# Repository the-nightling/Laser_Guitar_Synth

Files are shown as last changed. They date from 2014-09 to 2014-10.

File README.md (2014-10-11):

Laser_Guitar_Synth
==================

The laser guitar synthesizer synthesizes guitar sounds using the Karplus-Strong algorithm.
An STM32F4 microcontroller is used.

The relevant pin connections can be found in the Hardware folder.
Six laser diodes were used to generate six lasers that are being used instead of actual guitar strings. Those are paired with six photodiodes and fed into a multiplexer.

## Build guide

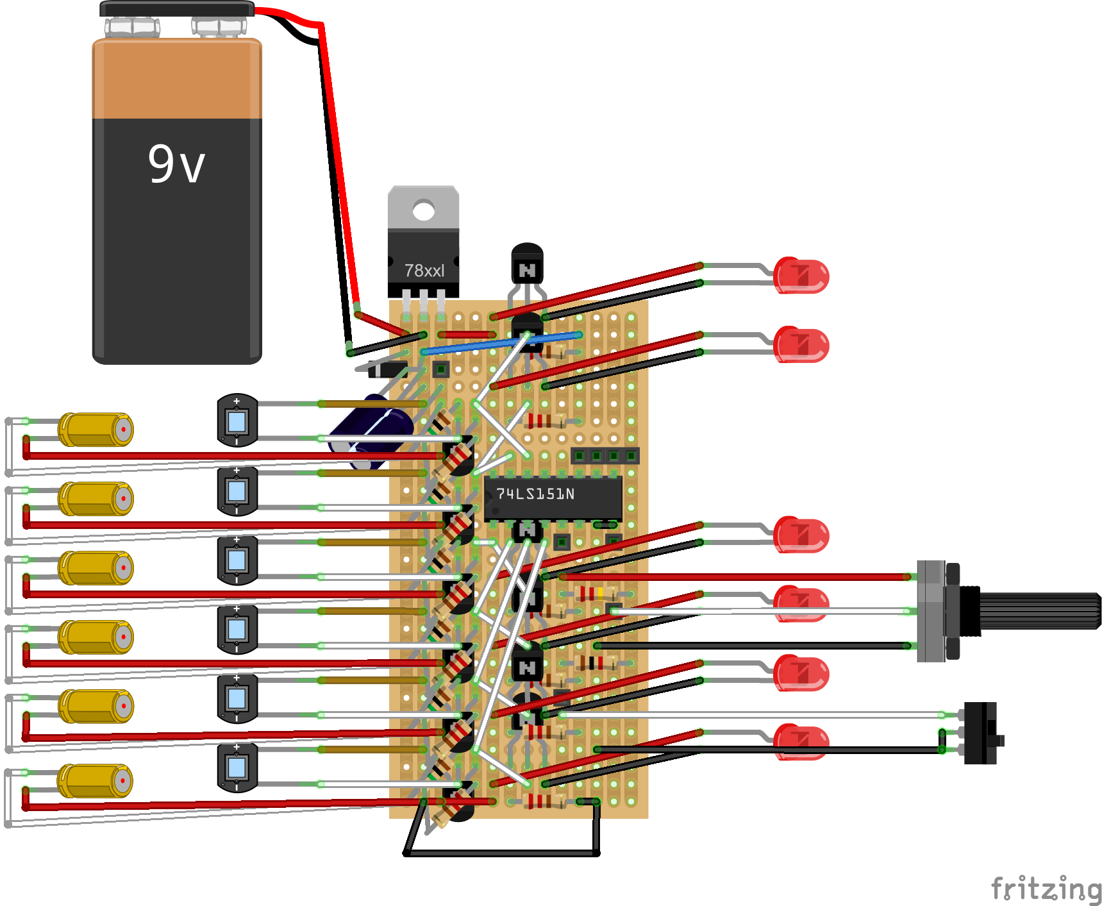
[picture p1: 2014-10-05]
Hardware/Veroboard Setup_bb.png

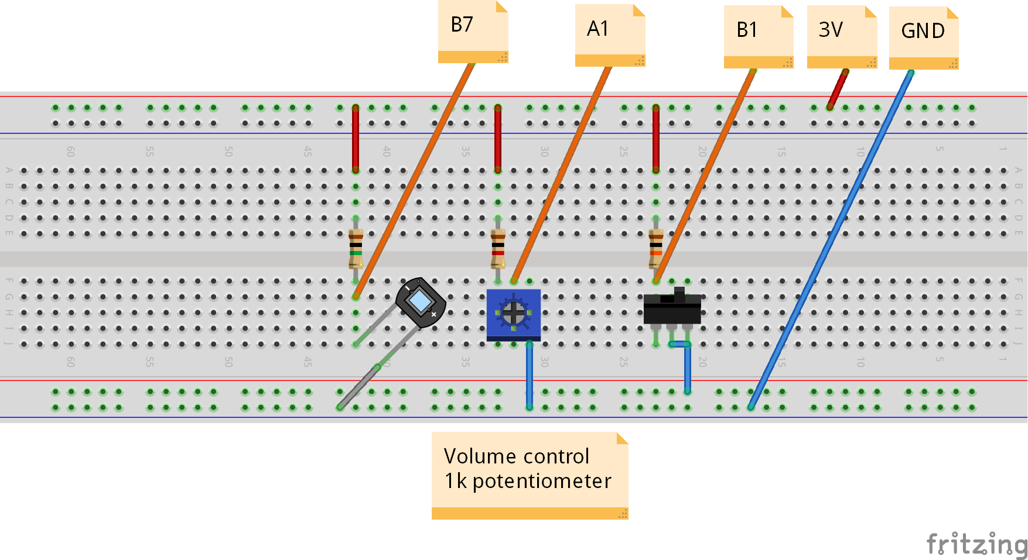
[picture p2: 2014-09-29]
Hardware/Breadboard Setup_bb.png

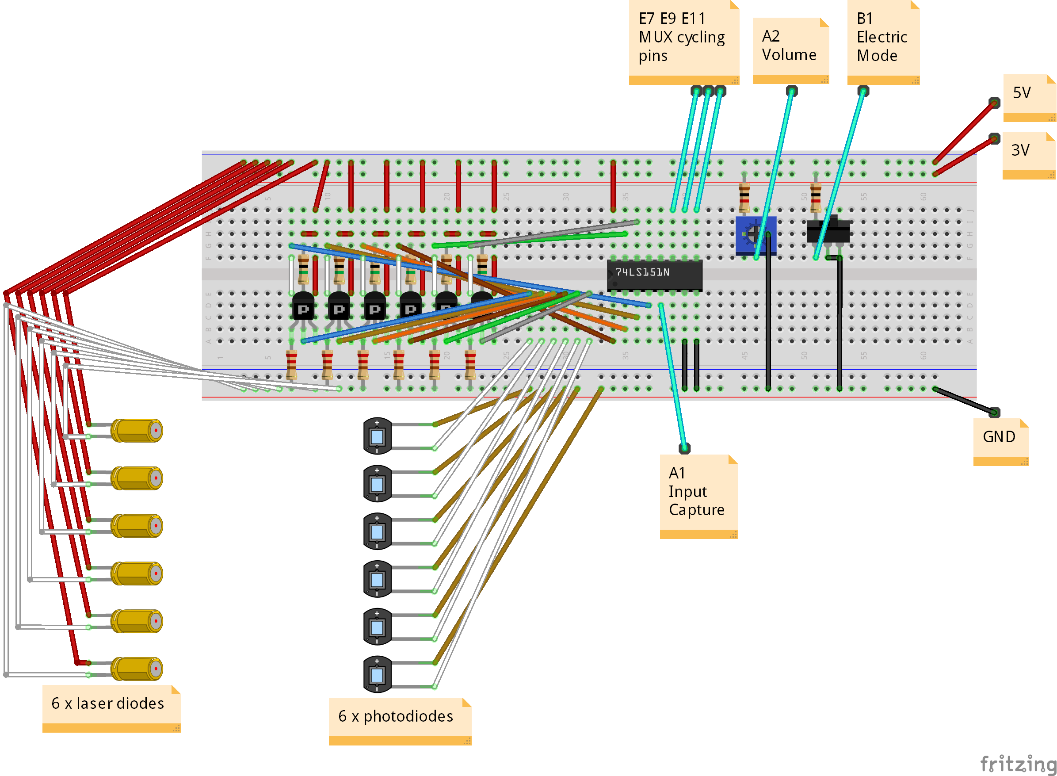
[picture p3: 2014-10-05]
Hardware/Breadboard Setup v2_bb.png

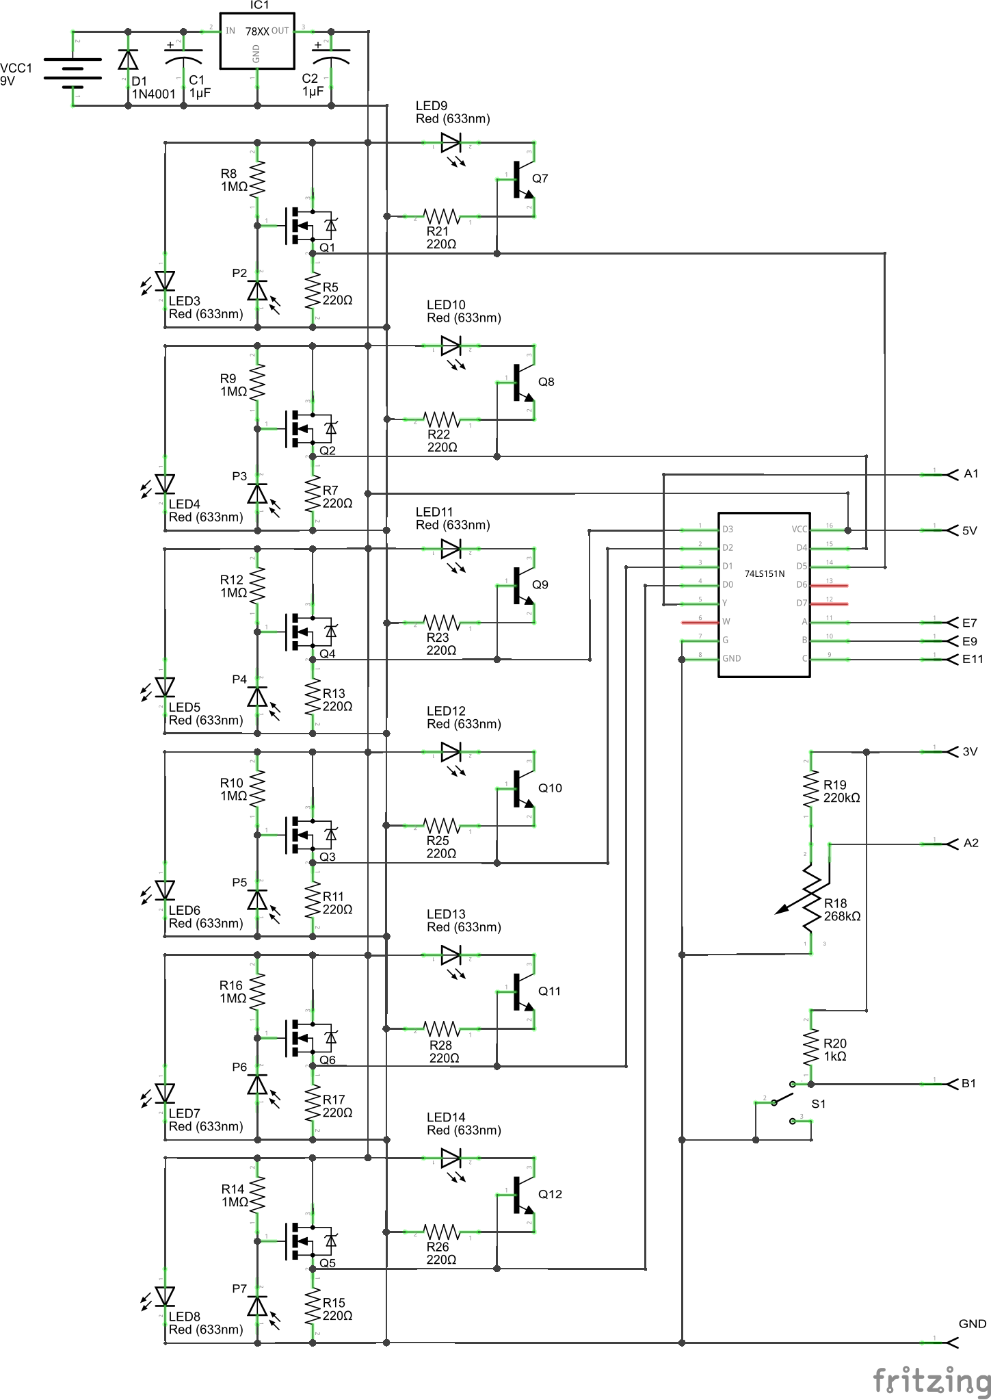
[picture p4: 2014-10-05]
Hardware/Veroboard Setup_schem.png

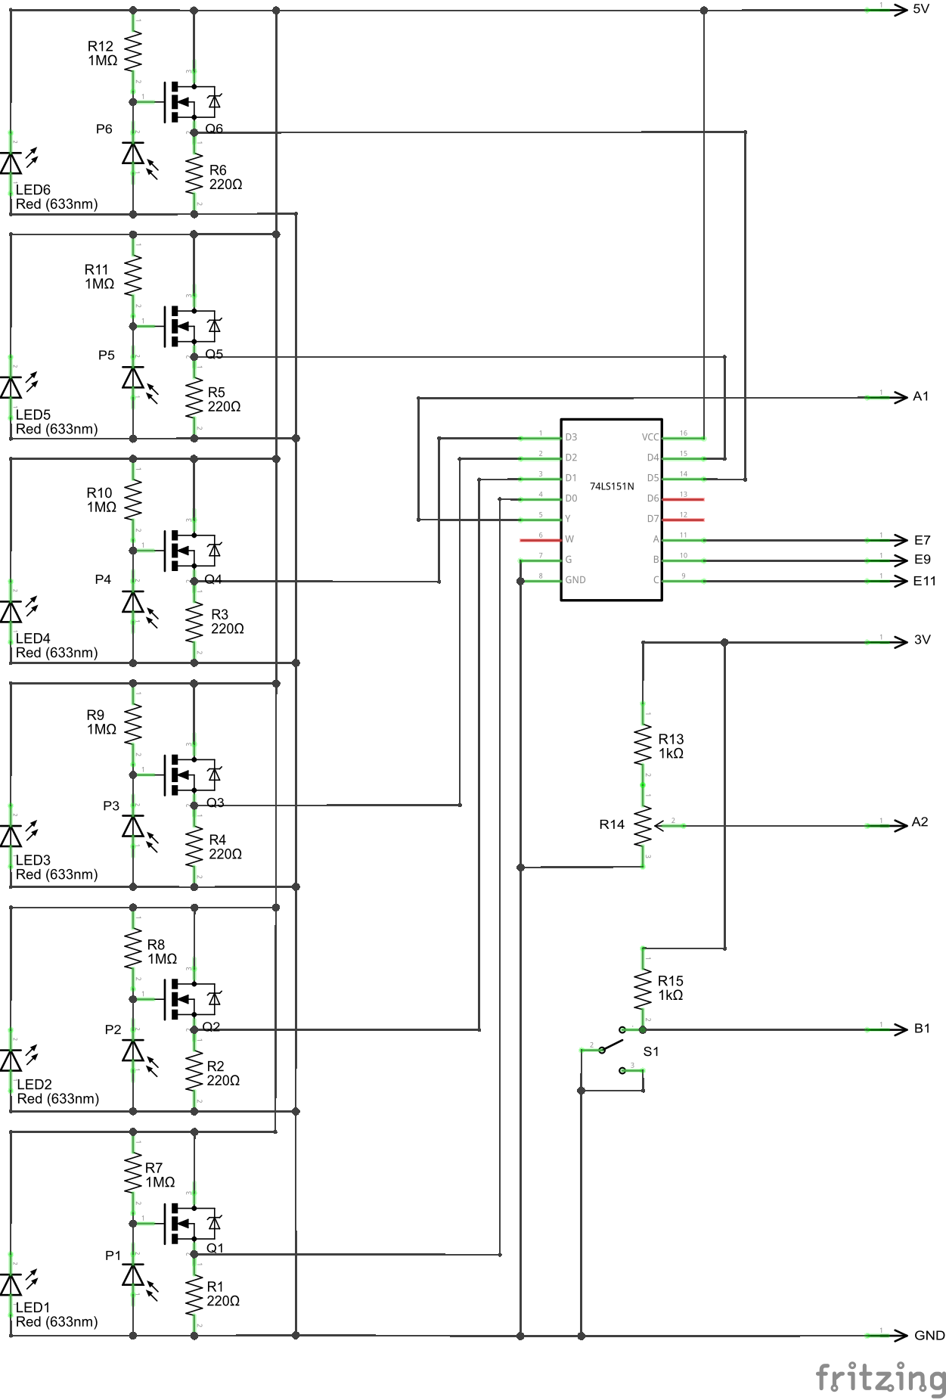
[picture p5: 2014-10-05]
Hardware/Breadboard Setup v2_schem.png

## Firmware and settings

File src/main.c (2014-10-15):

/**
 *****************************************************************************
 **
 ** EEE3074W Project
 ** Laser Guitar Synthesizer
 ** Team 10
 **
 ** Description:
 ** Upon an external trigger (plucking of laser string), the software:
 ** (i)   checks the volume, mode, note frequency and octave parameters
 ** (ii)  synthesizes the note corresponding to those parameters and saves the result in a buffer
 ** (iii) outputs the buffer contents via the on-board audio DAC
 **
 *****************************************************************************
 */

/* Includes */
#include "stm32f4xx.h"
#include "stm32f4_discovery.h"
#include "codec.h"
#include <math.h>

/* Private Macros */
#define OUTBUFFERSIZE 44100
#define DACBUFFERSIZE 600

/* Private Global Variables */
__IO uint8_t outBuffer[OUTBUFFERSIZE];	// stores synthesized note waveform
__IO uint16_t ADC1_val[7];				// volume knob and fret buttons voltage
__IO uint16_t IC1Value = 0;				// Stores length of beam break pulse (isn't being used)
__IO uint8_t string_plucked = 0;		// flag to indicate when a string was plucked
__IO uint8_t mux_enable = 1;			// flag to indicate if multiplexer is cycling through select pins
__IO uint8_t electrify = 0;				// flag to set/reset electric (reverb) mode
__IO uint8_t counter = 0;
__IO uint8_t stringNo = 6;				// default guitar string (laser)
__IO uint8_t octave = 4;				// default octave
__IO float noteFreq = 20.6;				// default note frequency
__IO float amplitude = 1.0;		// controls volume via duration of pluck (length of beam break can potentially change volume; not being used)
__IO float volume = 0.5;		// controls volume via volume knob
__IO uint32_t duration = 44100;	// controls duration of note


// Guitar notes buffer length reference
// C = 16.35	          C3 = 338, C4 = 168
// C#= 17.32	          C#3= 318, C#4= 160
// D = 18.35	          D3 = 300, D4 = 150
// Eb= 19.45	          Eb3= 284, Eb4= 142
// E = 20.60	E2 = 536, E3 = 268, E4 = 134
// F = 21.83	F2 = 506, F3 = 252, F4 = 126
// F#= 23.12	F#2= 476, F#3= 238, F#4= 120
// G = 24.50	G2 = 450, G3 = 226, G4 = 112
// G#= 25.96	G#2= 424, G#3= 212, G#4= 106
// A = 27.50	A2 = 400, A3 = 200
// Bb= 29.14	Bb2= 378, Bb3= 190
// B = 30.87	B2 = 358, B3 = 178

//				Free		Fret1		Fret2		Fret3		Fret4
// String 6:	E2 = 536	F2 = 506	F#2= 476	G2 = 450	G#2= 424
// String 5:	A2 = 400	Bb2= 378	B2 = 358	C3 = 338	C#3= 318
// String 4:	D3 = 300	Eb3= 284	E3 = 268	F3 = 252	F#3= 238
// String 3:	G3 = 226	G#3= 212	A3 = 200	Bb3= 190	B3 = 178
// String 2:	B3 = 178	C4 = 168	C#4= 160	D4 = 150	Eb4= 142
// String 1:	E4 = 134	F4 = 126	F#4= 120	G4 = 112	G#4= 106

/* Private Function Prototypes */
void RCC_Configuration(void);
void GPIO_Configuration(void);
void Timer_Configuration(void);
void NVIC_Configuration(void);
void RNG_Configuration(void);
void ADC_Configuration(void);



/**
 **===========================================================================
 **
 **  IRQ Handlers
 **
 **===========================================================================
 */
/*
 * Cycle through 6 laser strings via multiplexer
 */
void TIM2_IRQHandler(void)
{
	// Clear TIM2 interrupt pending bit
	if(TIM_GetITStatus(TIM2, TIM_IT_Update) != RESET)
	{
		TIM_ClearITPendingBit(TIM2, TIM_IT_Update);

		// cycle through 6 multiplexer pins while mux flag is high
		if (mux_enable == 1) {

			// set multiplexer input select pins
			if(counter == 0)
			{
				GPIOE->BSRRH = GPIO_Pin_7;
				GPIOE->BSRRH = GPIO_Pin_9;
				GPIOE->BSRRH = GPIO_Pin_11;
			}
			else if (counter == 1)
			{
				GPIOE->BSRRL = GPIO_Pin_7;
				GPIOE->BSRRH = GPIO_Pin_9;
				GPIOE->BSRRH = GPIO_Pin_11;
			}
			else if (counter == 2)
			{
				GPIOE->BSRRH = GPIO_Pin_7;
				GPIOE->BSRRL = GPIO_Pin_9;
				GPIOE->BSRRH = GPIO_Pin_11;
			}
			else if (counter == 3)
			{
				GPIOE->BSRRL = GPIO_Pin_7;
				GPIOE->BSRRL = GPIO_Pin_9;
				GPIOE->BSRRH = GPIO_Pin_11;
			}
			else if (counter == 4)
			{
				GPIOE->BSRRH = GPIO_Pin_7;
				GPIOE->BSRRH = GPIO_Pin_9;
				GPIOE->BSRRL = GPIO_Pin_11;
			}
			else if (counter == 5)
			{
				GPIOE->BSRRL = GPIO_Pin_7;
				GPIOE->BSRRH = GPIO_Pin_9;
				GPIOE->BSRRL = GPIO_Pin_11;
			}

			counter++;
			if(counter > 5)
			{
				counter = 0;
			}
		}
	}
}

/*
 * Trigger if laser string is plucked
 */
void TIM5_IRQHandler(void)
{
	// Clear TIM5 Capture compare interrupt pending bit (falling edge)
	if(TIM_GetITStatus(TIM5, TIM_IT_CC1) == SET) {
		TIM_ClearITPendingBit(TIM5, TIM_IT_CC1);

		// re-enable multiplexer pin cycling when laser is no longer broken
		mux_enable = 1;
	}

	// Clear TIM5 Capture compare interrupt pending bit (rising edge)
	if(TIM_GetITStatus(TIM5, TIM_IT_CC2) == SET) {
		TIM_ClearITPendingBit(TIM5, TIM_IT_CC2);

		// disable multiplexer pin cycling as soon as laser is broken
		mux_enable = 0;

		// Get the Input Capture value
		//IC1Value = TIM_GetCapture1(TIM5);		// for volume controlled by duration of pluck (not being used)
		volume = 10*((float)ADC1_val[0]/59456);

		//amplitude = (float)(volume)*(1-(float)IC1Value/0xFFFFFFFF);
		amplitude = (float)(volume);

		// Let us know that the string was plucked
		string_plucked = 1;
	}
}

/*
 * Electric mode switch stuff
 */
void EXTI1_IRQHandler(void)
{
	if(EXTI_GetITStatus(EXTI_Line1) != RESET)
	{
		if(GPIO_ReadInputDataBit(GPIOB, GPIO_Pin_1) == SET)
		{
			electrify = 1;
		}
		else
		{
			electrify = 0;
		}

		/* Clear the EXTI line 1 pending bit */
		EXTI_ClearITPendingBit(EXTI_Line1);
	}
}

/**
 **===========================================================================
 **
 **  Abstract: main program
 **
 **===========================================================================
 */
int main(void)
{
	volatile uint32_t sampleCounter = 0;
	volatile int16_t sample = 0;
	volatile uint8_t DACBuffer[DACBUFFERSIZE];		// buffer used for synthesis algorithm; length determines note frequency and octave
	volatile uint8_t tempBuffer[DACBUFFERSIZE];
	volatile uint8_t noiseBuffer[DACBUFFERSIZE];

	// Calculation of buffer length corresponding to note that needs to be played (using default values here)
	// duration/(note frequency x 2^octave) if odd, add 1
	uint16_t DACBufferSize = (uint16_t)(((float)44100/(noteFreq*pow(2, octave))));
	if(DACBufferSize & 0x00000001)
		DACBufferSize +=1;

	// initialising peripherals
	SystemInit();
	RCC_Configuration();
	GPIO_Configuration();
	Timer_Configuration();
	NVIC_Configuration();
	RNG_Configuration();
	codec_init();
	codec_ctrl_init();
	ADC_Configuration();

	// Fill buffer with white noise
	uint16_t n, m;
	uint32_t random = 0;
	for (n = 0; n<DACBUFFERSIZE; n++)
	{
		while(RNG_GetFlagStatus(RNG_FLAG_DRDY) == 0);
		random = RNG_GetRandomNumber();
		noiseBuffer[n] = (uint8_t)(((0xFF+1)/2)*(2*(((float)random)/0xFFFFFFFF)));
		DACBuffer[n] = noiseBuffer[n];
		RNG_ClearFlag(RNG_FLAG_DRDY);
	}

	// infinite loop contains synthesis and output code
	while(1)
	{
		if(string_plucked == 1)
		{
			// reset timer flag
			string_plucked = 0;

			// set note based on laser string plucked
			// and fret button pushed
			if(counter == 5)		// D3(String 2)
			{
				if(ADC1_val[5] > 60000)			// B3
				{
					noteFreq = 30.87;
					octave = 3;
				}
				else if(ADC1_val[5] > 42000)	// Eb4
				{
					noteFreq = 19.45;
					octave = 4;
				}
				else if(ADC1_val[5] > 39000)	// D4
				{
					noteFreq = 18.35;
					octave = 4;
				}
				else if(ADC1_val[5] > 35000)	// C#4
				{
					noteFreq = 17.32;
					octave = 4;
				}
				else if(ADC1_val[5] > 32000)	// C4
				{
					noteFreq = 16.35;
					octave = 4;
				}
				else							// B3
				{
					noteFreq = 30.87;
					octave = 3;
				}
			}
			else if(counter == 4)	// D2(String 3)
			{
				if(ADC1_val[4] > 60000)			// G3
				{
					noteFreq = 24.50;
					octave = 3;
				}
				else if(ADC1_val[4] > 42000)	// B3
				{
					noteFreq = 30.87;
					octave = 3;
				}
				else if(ADC1_val[4] > 39000)	// Bb3
				{
					noteFreq = 29.14;
					octave = 3;
				}
				else if(ADC1_val[4] > 35000)	// A3
				{
					noteFreq = 27.50;
					octave = 3;
				}
				else if(ADC1_val[4] > 32000)	// G#3
				{
					noteFreq = 25.96;
					octave = 3;
				}
				else							// G3
				{
					noteFreq = 24.50;
					octave = 3;
				}
			}
			else if(counter == 3)	// D1(String 4)
			{
				if(ADC1_val[3] > 60000)			// D3
				{
					noteFreq = 18.35;
					octave = 3;
				}
				else if(ADC1_val[3] > 42000)	// F#3
				{
					noteFreq = 23.12;
					octave = 3;
				}
				else if(ADC1_val[3] > 39000)	// F3
				{
					noteFreq = 21.83;
					octave = 3;
				}
				else if(ADC1_val[3] > 35000)	// E3
				{
					noteFreq = 20.60;
					octave = 3;
				}
				else if(ADC1_val[3] > 32000)	// Eb3
				{
					noteFreq = 19.45;
					octave = 3;
				}
				else							// D3
				{
					noteFreq = 18.35;
					octave = 3;
				}
			}
			else if(counter == 2)	// D0(String 5)
			{
				if(ADC1_val[2] > 60000)			// A2
				{
					noteFreq = 27.50;
					octave = 2;
				}
				else if(ADC1_val[2] > 42000)	// C#3
				{
					noteFreq = 17.32;
					octave = 3;
				}
				else if(ADC1_val[2] > 39000)	// C3
				{
					noteFreq = 16.35;
					octave = 3;
				}
				else if(ADC1_val[2] > 35000)	// B2
				{
					noteFreq = 30.87;
					octave = 2;
				}
				else if(ADC1_val[2] > 32000)	// Bb2
				{
					noteFreq = 29.14;
					octave = 2;
				}
				else							// A2
				{
					noteFreq = 27.50;
					octave = 2;
				}
			}
			else if(counter == 1)	// D5(String 6)
			{
				if(ADC1_val[1] > 60000)			// E2
				{
					noteFreq = 20.60;
					octave = 2;
				}
				else if(ADC1_val[1] > 42000)	// G#2
				{
					noteFreq = 25.96;
					octave = 2;
				}
				else if(ADC1_val[1] > 39000)	// G2
				{
					noteFreq = 24.50;
					octave = 2;
				}
				else if(ADC1_val[1] > 35000)	// F#2
				{
					noteFreq = 23.12;
					octave = 2;
				}
				else if(ADC1_val[1] > 32000)	// F2
				{
					noteFreq = 21.83;
					octave = 2;
				}
				else							// E2
				{
					noteFreq = 20.60;
					octave = 2;
				}
			}
			else if(counter == 0)	// D4(String 1)
			{
				if(ADC1_val[6] > 60000)			// E4
				{
					noteFreq = 20.60;
					octave = 4;
				}
				else if(ADC1_val[6] > 42000)	// G#4
				{
					noteFreq = 25.96;
					octave = 4;
				}
				else if(ADC1_val[6] > 39000)	// G4
				{
					noteFreq = 24.50;
					octave = 4;
				}
				else if(ADC1_val[6] > 35000)	// F#4
				{
					noteFreq = 23.12;
					octave = 4;
				}
				else if(ADC1_val[6] > 32000)	// F4
				{
					noteFreq = 21.83;
					octave = 4;
				}
				else							// E4
				{
					noteFreq = 20.60;
					octave = 4;
				}
			}

			// update buffer length according to note desired
			DACBufferSize = (uint16_t)(((float)44100/(noteFreq*pow(2, octave))));
			if(DACBufferSize & 0x00000001)
				DACBufferSize +=1;

			// Synthesize note
			volatile uint16_t i;
			volatile uint16_t j = 0;
			for(i = 0; i < duration; i++)
			{
				// send silence to audio DAC while note is being synthesized (gets rid of static noise)
				if (SPI_I2S_GetFlagStatus(CODEC_I2S, SPI_I2S_FLAG_TXE))
				{
					SPI_I2S_SendData(CODEC_I2S, 0);
				}

				// karplus-strong algorithm
				if(j != DACBufferSize-1)
				{
					tempBuffer[j] = (uint8_t)(((DACBuffer[j]+DACBuffer[j+1])/2.0)*0.999);
				}
				else
				{
					tempBuffer[j] = (uint8_t)(((DACBuffer[j]+tempBuffer[0])/2.0)*0.999);
				}
				outBuffer[i] = (uint8_t)tempBuffer[j];

				// electric mode (clips waveform)
				if(electrify == 1 && outBuffer[i] >= 105)
				{
					//outBuffer[i] = 55;
				}
				else if(electrify == 1 && outBuffer[i] < 105)
				{
					outBuffer[i] = 180;
				}

				j++;

				// values synthesized are re-used to synthesize newer values (simulates a queue)
				if(j == DACBufferSize)
				{
					for(n=0; n < DACBufferSize; n++)
					{
						DACBuffer[n] = tempBuffer[n];

						// send silence to audio DAC while note is being synthesized (gets rid of static noise)
						if (SPI_I2S_GetFlagStatus(CODEC_I2S, SPI_I2S_FLAG_TXE))
						{
							SPI_I2S_SendData(CODEC_I2S, 0);
						}
					}
					j = 0;
				}

			}

			// determines where in the output buffer we should start sending values to audioDAC
			// helps get rid of some delay
			n = 1000;

			// output sound
			while(1)
			{
				// if a new string has been plucked, stop outputting and re-start synthesis
				if(string_plucked == 1) {
					break;
				}

				// output sound
				if (SPI_I2S_GetFlagStatus(CODEC_I2S, SPI_I2S_FLAG_TXE))
				{
					SPI_I2S_SendData(CODEC_I2S, sample);

					//only update on every second sample to ensure that L & R channels have the same sample value
					if (sampleCounter & 0x00000001)
					{
						if(n >= duration)
						{
							n = 0;

							break;	// exit loop when note ends
						}

						sample = (int16_t)(amplitude*outBuffer[n]);

						// change increment value to change frequency (should not be used)
						n += 1;
					}
					sampleCounter++;
				}

				if (sampleCounter == 96000)
				{
					sampleCounter = 0;
				}
			}

			// fill buffer with white noise again
			for(m=0; m < DACBufferSize; m++)
			{
				DACBuffer[m] = noiseBuffer[m];

				// send silence to audio DAC while no note is being played (gets rid of static noise)
				if (SPI_I2S_GetFlagStatus(CODEC_I2S, SPI_I2S_FLAG_TXE))
				{
					SPI_I2S_SendData(CODEC_I2S, 0);
				}
			}
		}

		// while laser not broken
		// send silence to audio DAC while no note is being played (gets rid of static noise)
		if (SPI_I2S_GetFlagStatus(CODEC_I2S, SPI_I2S_FLAG_TXE))
		{
			SPI_I2S_SendData(CODEC_I2S, 0);
		}
	}
}



void RCC_Configuration(void)
{
	// enable clock for GPIOA, GPIOB, GPIOC, GPIOE and DMA2
	RCC_AHB1PeriphClockCmd(RCC_AHB1Periph_GPIOA|RCC_AHB1Periph_GPIOB|RCC_AHB1Periph_GPIOC|RCC_AHB1Periph_GPIOE|RCC_AHB1Periph_DMA2, ENABLE);

	// enable clock for Random Number Generator
	RCC_AHB2PeriphClockCmd(RCC_AHB2Periph_RNG, ENABLE);

	// enable clock for timers 2 and 5
	RCC_APB1PeriphClockCmd(RCC_APB1Periph_TIM5|RCC_APB1Periph_TIM2, ENABLE);

	// enable clock for SYSCFG for EXTI
	RCC_APB2PeriphClockCmd(RCC_APB2Periph_SYSCFG|RCC_APB2Periph_ADC1, ENABLE);
}

void GPIO_Configuration(void)
{
	GPIO_InitTypeDef GPIO_InitStructure;

	/* TIM5 channel2 configuration : PA.01 */
	GPIO_InitStructure.GPIO_Pin   = GPIO_Pin_1;
	GPIO_InitStructure.GPIO_Mode  = GPIO_Mode_AF;
	GPIO_InitStructure.GPIO_Speed = GPIO_Speed_100MHz;
	GPIO_InitStructure.GPIO_OType = GPIO_OType_PP;
	GPIO_InitStructure.GPIO_PuPd  = GPIO_PuPd_NOPULL;

	GPIO_Init(GPIOA, &GPIO_InitStructure);

	/* Connect TIM pin to AF2 */
	GPIO_PinAFConfig(GPIOA, GPIO_PinSource1, GPIO_AF_TIM5);

	/* Electric mode switch configuration: PB.01 */
	GPIO_InitStructure.GPIO_Pin = GPIO_Pin_1;
	GPIO_InitStructure.GPIO_Mode = GPIO_Mode_IN;
	GPIO_InitStructure.GPIO_PuPd = GPIO_PuPd_NOPULL;
	GPIO_Init(GPIOB, &GPIO_InitStructure);

	/* Connect EXTI Line to GPIO Pin */
	SYSCFG_EXTILineConfig(EXTI_PortSourceGPIOB, EXTI_PinSource1);

	EXTI_InitTypeDef EXTI_InitStructure;

	/* Configure EXTI line */
	EXTI_InitStructure.EXTI_Line = EXTI_Line1;
	EXTI_InitStructure.EXTI_Mode = EXTI_Mode_Interrupt;
	EXTI_InitStructure.EXTI_Trigger = EXTI_Trigger_Rising_Falling;
	EXTI_InitStructure.EXTI_LineCmd = ENABLE;
	EXTI_Init(&EXTI_InitStructure);

	/* Volume pin configuration */
	GPIO_InitStructure.GPIO_Mode = GPIO_Mode_AN;
	GPIO_InitStructure.GPIO_Pin = GPIO_Pin_2 | GPIO_Pin_3;
	GPIO_InitStructure.GPIO_PuPd = GPIO_PuPd_NOPULL;

	GPIO_Init(GPIOA, &GPIO_InitStructure);

	GPIO_InitStructure.GPIO_Mode = GPIO_Mode_AN;
	GPIO_InitStructure.GPIO_Pin = GPIO_Pin_0;
	GPIO_InitStructure.GPIO_PuPd = GPIO_PuPd_NOPULL;

	GPIO_Init(GPIOB, &GPIO_InitStructure);

	GPIO_InitStructure.GPIO_Mode = GPIO_Mode_AN;
	GPIO_InitStructure.GPIO_Pin = GPIO_Pin_1 | GPIO_Pin_2 | GPIO_Pin_4 | GPIO_Pin_5;
	GPIO_InitStructure.GPIO_PuPd = GPIO_PuPd_NOPULL;

	GPIO_Init(GPIOC, &GPIO_InitStructure);

	/* Multiplexer switching configuration */
	GPIO_InitStructure.GPIO_Pin = GPIO_Pin_7;
	GPIO_InitStructure.GPIO_Mode = GPIO_Mode_OUT;
	GPIO_InitStructure.GPIO_OType = GPIO_OType_PP;
	GPIO_InitStructure.GPIO_PuPd = GPIO_PuPd_UP;
	GPIO_InitStructure.GPIO_Speed = GPIO_Speed_50MHz;
	GPIO_Init(GPIOE, &GPIO_InitStructure);

	GPIO_InitStructure.GPIO_Pin = GPIO_Pin_9;
	GPIO_Init(GPIOE, &GPIO_InitStructure);

	GPIO_InitStructure.GPIO_Pin = GPIO_Pin_11;
	GPIO_Init(GPIOE, &GPIO_InitStructure);

}

void NVIC_Configuration(void)
{
	NVIC_InitTypeDef NVIC_InitStructure;
	NVIC_PriorityGroupConfig(NVIC_PriorityGroup_4);

	/* Enable the TIM5 global Interrupt */
	NVIC_InitStructure.NVIC_IRQChannel = TIM5_IRQn;
	NVIC_InitStructure.NVIC_IRQChannelPreemptionPriority = 0;
	NVIC_InitStructure.NVIC_IRQChannelSubPriority = 1;
	NVIC_InitStructure.NVIC_IRQChannelCmd = ENABLE;

	NVIC_Init(&NVIC_InitStructure);

	/* Enable and set Button EXTI Interrupt to the lowest priority */
	NVIC_InitStructure.NVIC_IRQChannel = EXTI1_IRQn;
	NVIC_InitStructure.NVIC_IRQChannelPreemptionPriority = 1;
	NVIC_InitStructure.NVIC_IRQChannelSubPriority = 1;
	NVIC_InitStructure.NVIC_IRQChannelCmd = ENABLE;

	NVIC_Init(&NVIC_InitStructure);

	/* Enable the TIM2 global Interrupt*/
	NVIC_InitStructure.NVIC_IRQChannel = TIM2_IRQn;
	NVIC_InitStructure.NVIC_IRQChannelPreemptionPriority = 2;
	NVIC_InitStructure.NVIC_IRQChannelSubPriority = 1;
	NVIC_InitStructure.NVIC_IRQChannelCmd = ENABLE;

	NVIC_Init(&NVIC_InitStructure);
}

void Timer_Configuration(void)
{
	TIM_ICInitTypeDef  TIM_ICInitStructure;
	TIM_TimeBaseInitTypeDef  TIM_TimeBaseStructure;

	TIM_TimeBaseStructure.TIM_Period = 0xFFFFFFFF;
	TIM_TimeBaseStructure.TIM_Prescaler = 2000;
	TIM_TimeBaseStructure.TIM_ClockDivision = 0;
	TIM_TimeBaseStructure.TIM_CounterMode = TIM_CounterMode_Up;
	TIM_TimeBaseInit(TIM5, &TIM_TimeBaseStructure);

	TIM_ICInitStructure.TIM_Channel = TIM_Channel_2;
	TIM_ICInitStructure.TIM_ICPolarity = TIM_ICPolarity_Rising;
	TIM_ICInitStructure.TIM_ICSelection = TIM_ICSelection_DirectTI;
	TIM_ICInitStructure.TIM_ICPrescaler = TIM_ICPSC_DIV1;
	TIM_ICInitStructure.TIM_ICFilter = 0x3;

	TIM_PWMIConfig(TIM5, &TIM_ICInitStructure);

	/* Select the TIM5 Input Trigger: TI2FP2 */
	TIM_SelectInputTrigger(TIM5, TIM_TS_TI2FP2);

	/* Select the slave Mode: Reset Mode */
	TIM_SelectSlaveMode(TIM5, TIM_SlaveMode_Reset);
	TIM_SelectMasterSlaveMode(TIM5,TIM_MasterSlaveMode_Enable);

	/* TIM enable counter */
	TIM_Cmd(TIM5, ENABLE);

	/* Enable the CC1 Interrupt Request */
	TIM_ITConfig(TIM5, TIM_IT_CC1 | TIM_IT_CC2, ENABLE);

	// TIM2 Setup

	TIM_TimeBaseStructInit(&TIM_TimeBaseStructure);

	TIM_TimeBaseStructure.TIM_Period = 840-1;
	TIM_TimeBaseStructure.TIM_Prescaler = 1-1;
	TIM_TimeBaseStructure.TIM_ClockDivision = 0;
	TIM_TimeBaseStructure.TIM_CounterMode = TIM_CounterMode_Up;

	TIM_TimeBaseInit(TIM2, &TIM_TimeBaseStructure);

	/* Enable the Interrupt Request */
	TIM_ITConfig(TIM2, TIM_IT_Update, ENABLE);

	TIM_Cmd(TIM2, ENABLE);
}


void ADC_Configuration(void)
{
	ADC_InitTypeDef ADC_InitStruct;
	ADC_CommonInitTypeDef ADC_CommonInitStruct;
	DMA_InitTypeDef DMA_InitStruct;

	DMA_InitStruct.DMA_BufferSize = 7;
	DMA_InitStruct.DMA_Channel = DMA_Channel_0;
	DMA_InitStruct.DMA_DIR = DMA_DIR_PeripheralToMemory;
	DMA_InitStruct.DMA_FIFOMode = DMA_FIFOMode_Disable;
	DMA_InitStruct.DMA_FIFOThreshold = DMA_FIFOThreshold_HalfFull;
	DMA_InitStruct.DMA_Memory0BaseAddr = (uint32_t)&ADC1_val[0];
	DMA_InitStruct.DMA_MemoryBurst = DMA_MemoryBurst_Single;
	DMA_InitStruct.DMA_MemoryDataSize = DMA_MemoryDataSize_HalfWord;
	DMA_InitStruct.DMA_MemoryInc = DMA_MemoryInc_Enable;
	DMA_InitStruct.DMA_Mode = DMA_Mode_Circular;
	DMA_InitStruct.DMA_PeripheralBaseAddr = (uint32_t) &ADC1->DR;
	DMA_InitStruct.DMA_PeripheralBurst = DMA_PeripheralBurst_Single;
	DMA_InitStruct.DMA_PeripheralDataSize = DMA_PeripheralDataSize_HalfWord;
	DMA_InitStruct.DMA_PeripheralInc = DMA_PeripheralInc_Disable;
	DMA_InitStruct.DMA_Priority = DMA_Priority_High;
	DMA_Init(DMA2_Stream4, &DMA_InitStruct);
	DMA_Cmd(DMA2_Stream4, ENABLE);

	ADC_CommonInitStruct.ADC_DMAAccessMode = ADC_DMAAccessMode_Disabled;
	ADC_CommonInitStruct.ADC_Mode = ADC_Mode_Independent;
	ADC_CommonInitStruct.ADC_Prescaler = ADC_Prescaler_Div2;
	ADC_CommonInitStruct.ADC_TwoSamplingDelay = ADC_TwoSamplingDelay_5Cycles;
	ADC_CommonInit(&ADC_CommonInitStruct);

	ADC_InitStruct.ADC_ContinuousConvMode = ENABLE;
	ADC_InitStruct.ADC_DataAlign = ADC_DataAlign_Right;
	ADC_InitStruct.ADC_ExternalTrigConv = ADC_ExternalTrigConvEdge_None;
	ADC_InitStruct.ADC_ExternalTrigConv = ADC_ExternalTrigConv_T1_CC1;
	ADC_InitStruct.ADC_NbrOfConversion = 7;
	ADC_InitStruct.ADC_Resolution = ADC_Resolution_12b;
	ADC_InitStruct.ADC_ScanConvMode = ENABLE;
	ADC_Init(ADC1, &ADC_InitStruct);

	ADC_RegularChannelConfig(ADC1, ADC_Channel_2, 1, ADC_SampleTime_112Cycles); //PA2
	ADC_RegularChannelConfig(ADC1, ADC_Channel_3, 2, ADC_SampleTime_112Cycles); //PA3
	ADC_RegularChannelConfig(ADC1, ADC_Channel_8, 3, ADC_SampleTime_112Cycles); //PB0
	ADC_RegularChannelConfig(ADC1, ADC_Channel_11, 4, ADC_SampleTime_112Cycles); //PC1
	ADC_RegularChannelConfig(ADC1, ADC_Channel_12, 5, ADC_SampleTime_112Cycles); //PC2
	ADC_RegularChannelConfig(ADC1, ADC_Channel_14, 6, ADC_SampleTime_112Cycles); //PC4
	ADC_RegularChannelConfig(ADC1, ADC_Channel_15, 7, ADC_SampleTime_112Cycles); //PC5

	ADC_DMARequestAfterLastTransferCmd(ADC1, ENABLE);
	ADC_DMACmd(ADC1, ENABLE);
	ADC_Cmd(ADC1, ENABLE);

	ADC_SoftwareStartConv(ADC1);
}

// Random Number Generator setup
void RNG_Configuration(void)
{
	RNG_Cmd(ENABLE);
}

/*
 * Callback used by stm32f4_discovery_audio_codec.c.
 * Refer to stm32f4_discovery_audio_codec.h for more info.
 */
void EVAL_AUDIO_TransferComplete_CallBack(uint32_t pBuffer, uint32_t Size){
	/* TODO, implement your code here */
	return;
}

/*
 * Callback used by stm324xg_eval_audio_codec.c.
 * Refer to stm324xg_eval_audio_codec.h for more info.
 */
uint16_t EVAL_AUDIO_GetSampleCallBack(void){
	/* TODO, implement your code here */
	return -1;
}

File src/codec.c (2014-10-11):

//*************************************
//
//  codec related functions
//
//	adapted from A.Finkelmeyer
//  http://www.mind-dump.net/configuring-the-stm32f4-discovery-for-audio
//
//*************************************

#include "codec.h"

void codec_init()
{
	// enable GPIOA, GPIOB, GPIOC, GPIOD clocks
	RCC_AHB1PeriphClockCmd(RCC_AHB1Periph_GPIOA | RCC_AHB1Periph_GPIOB | RCC_AHB1Periph_GPIOC | RCC_AHB1Periph_GPIOD, ENABLE);

	//enable I2S and I2C clocks
	RCC_APB1PeriphClockCmd(RCC_APB1Periph_I2C1 | RCC_APB1Periph_SPI3, ENABLE);
	RCC_PLLI2SCmd(ENABLE);

	// setting up GPIO for codec use
	GPIO_InitTypeDef PinInitStruct;
	GPIO_StructInit(&PinInitStruct);

	//Reset pin as GPIO
	PinInitStruct.GPIO_Pin = CODEC_RESET_PIN;	// pin D4 is codec reset pin
	PinInitStruct.GPIO_Mode = GPIO_Mode_OUT;
	PinInitStruct.GPIO_PuPd = GPIO_PuPd_DOWN;
	PinInitStruct.GPIO_OType = GPIO_OType_PP;
	PinInitStruct.GPIO_Speed = GPIO_Speed_50MHz;

	GPIO_Init(GPIOD, &PinInitStruct);
	GPIO_ResetBits(GPIOD, CODEC_RESET_PIN);	//keep Codec off for now

	// I2C pins
	PinInitStruct.GPIO_Pin = I2C_SCL_PIN | I2C_SDA_PIN;
	PinInitStruct.GPIO_Mode = GPIO_Mode_AF;
	PinInitStruct.GPIO_PuPd = GPIO_PuPd_NOPULL;
	PinInitStruct.GPIO_OType = GPIO_OType_OD;
	PinInitStruct.GPIO_Speed = GPIO_Speed_50MHz;
	GPIO_Init(GPIOB, &PinInitStruct);

	GPIO_PinAFConfig(GPIOB, GPIO_PinSource6, GPIO_AF_I2C1);	// pin B6 is SCL pin
	GPIO_PinAFConfig(GPIOB, GPIO_PinSource9, GPIO_AF_I2C1);	// pin B9 is SDA pin

	// I2S pins
	PinInitStruct.GPIO_Pin = I2S3_SCLK_PIN | I2S3_SD_PIN | I2S3_MCLK_PIN;	// pin C7 is MCLK; pin C10 is SCLK; pin C12 is SDIN
	PinInitStruct.GPIO_OType = GPIO_OType_PP;

	GPIO_Init(GPIOC, &PinInitStruct);
	GPIO_PinAFConfig(GPIOC, GPIO_PinSource7, GPIO_AF_SPI3);
	GPIO_PinAFConfig(GPIOC, GPIO_PinSource10, GPIO_AF_SPI3);
	GPIO_PinAFConfig(GPIOC, GPIO_PinSource12, GPIO_AF_SPI3);

	PinInitStruct.GPIO_Pin = I2S3_WS_PIN;	// pin A4 is LRCK/AIN1x

	GPIO_Init(GPIOA, &PinInitStruct);
	GPIO_PinAFConfig(GPIOA, GPIO_PinSource4, GPIO_AF_SPI3);


	I2S_InitTypeDef I2S_InitType;

	// configure I2S port
	SPI_I2S_DeInit(CODEC_I2S);
	I2S_InitType.I2S_AudioFreq = I2S_AudioFreq_48k;
	I2S_InitType.I2S_MCLKOutput = I2S_MCLKOutput_Enable;
	I2S_InitType.I2S_DataFormat = I2S_DataFormat_16b;
	I2S_InitType.I2S_Mode = I2S_Mode_MasterTx;
	I2S_InitType.I2S_Standard = I2S_Standard_Phillips;
	I2S_InitType.I2S_CPOL = I2S_CPOL_Low;

	I2S_Init(CODEC_I2S, &I2S_InitType);


	I2C_InitTypeDef I2C_InitType;

	// configure I2C port
	I2C_DeInit(CODEC_I2C);
	I2C_InitType.I2C_ClockSpeed = 100000;
	I2C_InitType.I2C_Mode = I2C_Mode_I2C;
	I2C_InitType.I2C_OwnAddress1 = CORE_I2C_ADDRESS;
	I2C_InitType.I2C_Ack = I2C_Ack_Enable;
	I2C_InitType.I2C_AcknowledgedAddress = I2C_AcknowledgedAddress_7bit;
	I2C_InitType.I2C_DutyCycle = I2C_DutyCycle_2;

	I2C_Cmd(CODEC_I2C, ENABLE);
	I2C_Init(CODEC_I2C, &I2C_InitType);
}


void codec_ctrl_init()
{
	uint32_t delaycount;
	uint8_t CodecCommandBuffer[5];

	uint8_t regValue = 0xFF;

	GPIO_SetBits(GPIOD, CODEC_RESET_PIN);
	delaycount = 1000000;
	while (delaycount > 0)
	{
		delaycount--;
	}
	//keep codec OFF
	CodecCommandBuffer[0] = CODEC_MAP_PLAYBACK_CTRL1;
	CodecCommandBuffer[1] = 0x01;
	send_codec_ctrl(CodecCommandBuffer, 2);

	//begin initialization sequence (p. 32)
	CodecCommandBuffer[0] = 0x00;
	CodecCommandBuffer[1] = 0x99;
	send_codec_ctrl(CodecCommandBuffer, 2);

	CodecCommandBuffer[0] = 0x47;
	CodecCommandBuffer[1] = 0x80;
	send_codec_ctrl(CodecCommandBuffer, 2);

	regValue = read_codec_register(0x32);

	CodecCommandBuffer[0] = 0x32;
	CodecCommandBuffer[1] = regValue | 0x80;
	send_codec_ctrl(CodecCommandBuffer, 2);

	regValue = read_codec_register(0x32);

	CodecCommandBuffer[0] = 0x32;
	CodecCommandBuffer[1] = regValue & (~0x80);
	send_codec_ctrl(CodecCommandBuffer, 2);

	CodecCommandBuffer[0] = 0x00;
	CodecCommandBuffer[1] = 0x00;
	send_codec_ctrl(CodecCommandBuffer, 2);
	//end of initialization sequence

	CodecCommandBuffer[0] = CODEC_MAP_PWR_CTRL2;
	CodecCommandBuffer[1] = 0xAF;
	send_codec_ctrl(CodecCommandBuffer, 2);

	CodecCommandBuffer[0] = CODEC_MAP_PLAYBACK_CTRL1;
	CodecCommandBuffer[1] = 0x70;
	send_codec_ctrl(CodecCommandBuffer, 2);

	CodecCommandBuffer[0] = CODEC_MAP_CLK_CTRL;
	CodecCommandBuffer[1] = 0x81; //auto detect clock
	send_codec_ctrl(CodecCommandBuffer, 2);

	CodecCommandBuffer[0] = CODEC_MAP_IF_CTRL1;
	CodecCommandBuffer[1] = 0x07;
	send_codec_ctrl(CodecCommandBuffer, 2);

	CodecCommandBuffer[0] = 0x0A;
	CodecCommandBuffer[1] = 0x00;
	send_codec_ctrl(CodecCommandBuffer, 2);

	CodecCommandBuffer[0] = 0x27;
	CodecCommandBuffer[1] = 0x00;
	send_codec_ctrl(CodecCommandBuffer, 2);

	CodecCommandBuffer[0] = 0x1A | CODEC_MAPBYTE_INC;
	CodecCommandBuffer[1] = 0x0A;
	CodecCommandBuffer[2] = 0x0A;
	send_codec_ctrl(CodecCommandBuffer, 3);

	CodecCommandBuffer[0] = 0x1F;
	CodecCommandBuffer[1] = 0x0F;
	send_codec_ctrl(CodecCommandBuffer, 2);

	CodecCommandBuffer[0] = CODEC_MAP_PWR_CTRL1;
	CodecCommandBuffer[1] = 0x9E;
	send_codec_ctrl(CodecCommandBuffer, 2);

	I2S_Cmd(CODEC_I2S, ENABLE);
}

void send_codec_ctrl(uint8_t controlBytes[], uint8_t numBytes)
{
	uint8_t bytesSent=0;

	while (I2C_GetFlagStatus(CODEC_I2C, I2C_FLAG_BUSY))
	{
		//just wait until no longer busy
	}

	I2C_GenerateSTART(CODEC_I2C, ENABLE);
	while (!I2C_GetFlagStatus(CODEC_I2C, I2C_FLAG_SB))
	{
		//wait for generation of start condition
	}
	I2C_Send7bitAddress(CODEC_I2C, CODEC_I2C_ADDRESS, I2C_Direction_Transmitter);
	while (!I2C_CheckEvent(CODEC_I2C, I2C_EVENT_MASTER_TRANSMITTER_MODE_SELECTED))
	{
		//wait for end of address transmission
	}
	while (bytesSent < numBytes)
	{
		I2C_SendData(CODEC_I2C, controlBytes[bytesSent]);
		bytesSent++;
		while (!I2C_CheckEvent(CODEC_I2C, I2C_EVENT_MASTER_BYTE_TRANSMITTING))
		{
			//wait for transmission of byte
		}
	}
	while(!I2C_GetFlagStatus(CODEC_I2C, I2C_FLAG_BTF))
	{
	    //wait until it's finished sending before creating STOP
	}
	I2C_GenerateSTOP(CODEC_I2C, ENABLE);

}
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

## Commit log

2014-09-02 Initial commit
    Single laser; Plucking the laser while a note is being outputted will change the note; Timer overflow not fixed
    [codec.c, codec.h, main.c]
2014-09-28 Added electric mode switching via interrupt
2014-09-29 Added volume control via ADC+DMA
2014-09-29 Added Fritzing breadboard layout to Hardware folder
    [Breadboard Setup.fzz]
2014-09-30 Added 6 strings breadboard layout to Hardware folder
    [Breadboard Setup v2.fzz]
2014-10-05 Changed output to occur on rising edge of MUX signal
    Also, added fritzing veroboard files
    [Breadboard Setup v2.fzz, Veroboard Setup.fzz]
2014-10-11 Added fret implementation
    [fret-vb.fzz, fret.fzz]
